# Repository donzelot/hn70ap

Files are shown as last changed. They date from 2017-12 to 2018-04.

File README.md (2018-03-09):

# hn70ap
Development board for modern packet radio on UHF

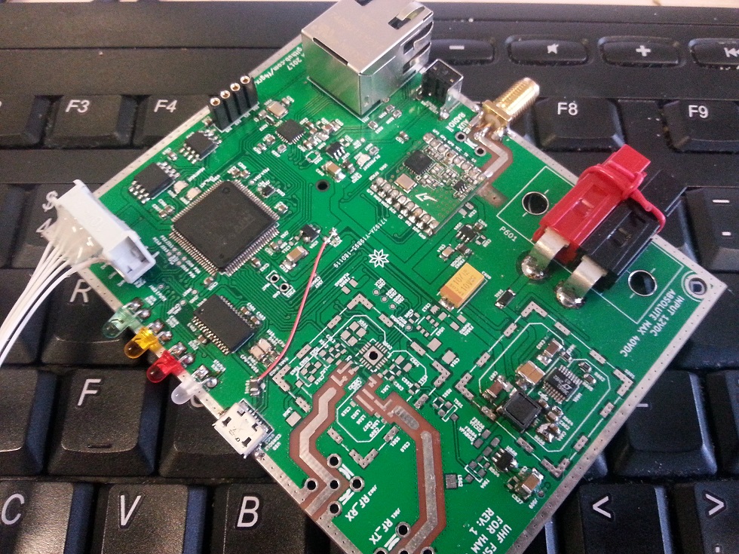
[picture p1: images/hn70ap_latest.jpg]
device under construction picture of device assembly


This repository contains sources for a few kicad projects and a NuttX board
support package for the board.

The main schematic and additional schematics and board designs are released
under the CERN OHL license.

Prerequisites
=============
 * linux (in 2017 there are many ways to get that)
 * a micro-usb cable to see the debug uart output
 * a jtag/swd adapter
 * a working openocd installation
 * an arm-none-eabi toolchain: https://launchpad.net/gcc-arm-embedded
 * to change the default configs: install kconfig-frontends
 
Mandatory: Install toolchain
============================
The arm-none-eabi toolchain provided by your distro probably does not work OK
(from experience). You may be lucky but this is not widespread enough. So we're
installing a really working toolchain.

The hardest way: compile a toolchain
------------------------------------
Hey this is a beginner guide. you dont need my guide if you are doing that. Help
yourself!

The hard way: download and install
----------------------------------

Open a bash shell console, then type commands ONE BY ONE (adapt them if you know
what you are doing):
```
$ cd $HOME
$ mkdir toolchains
$ cd toolchains
$ wget -O toolchain.tar.bz2 https://launchpad.net/gcc-arm-embedded/5.0/5-2016-q3-update/+download/gcc-arm-none-eabi-5_4-2016q3-20160926-linux.tar.bz2
$ tar jxvf toolchain.tar.bz2
$ cd $HOME
$ export PATH=$PATH:$HOME/toolchains/gcc-arm-none-eabi-5_4-2016q3/bin
```
The last line makes the ARM compiler available in your shell environment. You
can make that automatic, search the web. Otherwise you have to execute this last
line in each new shell window.

The easy way for ubuntu based distros
-------------------------------------

There is a ppa
```
sudo add-apt-repository ppa:team-gcc-arm-embedded/ppa
sudo apt-get update
sudo apt-get install gcc-arm-embedded
```

Toolchain test
--------------

You can test that the toolchain is functional by typing this command and
expecting this answer:
```
$ arm-none-eabi-gcc
arm-none-eabi-gcc: fatal error: no input files
compilation terminated.
```

If the command is not found, then the toolchain is not correctly installed and
the following will NOT work.

Optional: kconfig-frontends
===========================
Skip for now.
TODO, https://bitbucket.org/nuttx/tools, ./configure && make && make install

openocd
=======
Skip for now. TODO apt-get or ./configure && make && make install

Basic Build
===========
You need a working NuttX development environment:

```
$ mkdir nuttx
$ cd nuttx
$ git clone https://bitbucket.org/nuttx/nuttx
$ git clone https://bitbucket.org/nuttx/apps
$ cd nuttx
```
Then you can clone the board config in the proper directory
(This is NOT a submodule!)
```
$ cd configs
$ git clone https://github.com/f4grx/hn70ap
$ cd ..
```

Then choose any of the following test configurations
```
$ tools/configure.sh hn70ap/build/0_boot
```
```
$ tools/configure.sh hn70ap/build/1_memories
```
```
$ tools/configure.sh hn70ap/build/2_oled
```
And build the binary image for this board:
```
$ make
```
This should end up with an ELF binary 'nuttx', and binary images nuttx.bin

You then have to flash this binary on your board, probably with OpenOCD.

This will give you a basic shell, type help to show basic commands. This can be used to validate the behaviour of the board's CPU.

Flashing without JTAG
=====================

This will be possible later, when the bootloader is made ready. The hardware is ready to support that.
A python tool will build an update image from the nuttx elf output, and you will be able to send that image via ethernet or serial.

The bootloader is currently being written. The algorithm is as follows: At CPU startup, the external flash is initialized and searched for a firmware update, except when the button is pressed. If the update is valid, it is applied. If a failure happens, or the button has been pressed, enter a serial download mode. This mode will expect a firmware update image on the serial port and then write it to the external flash. Once done, an update attempt will be attempted after a reboot.

Advanced build
==============
More configurations will be added later that can be used to test ethernet, spi/i2c memories, etc

To modify the nuttx options type make menuconfig and mess around.

To get useful behaviour from this board you will need to add some applications that are not developed yet.

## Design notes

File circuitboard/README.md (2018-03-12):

Circuit board for hn70ap
========================

This folder contains the schematic of the KiCAD board used by the hn70ap
project.

It is released under the CERN OHL.

The project is completely standalone, it does not depend on ANY external
schematic library.

To open it you need kicad version 4.0.7.

Enclosure
=========
Any enclosure that can host a 80x100mm PCBs with connectors on both 100mm
sides is usable, for example a slotted extrusion box. I am using a
Multicomp MCREBS80 box from Farnell, which is in fact a Box Enclosures B2-080.
https://www.boxenclosures.com/product-category/bex-series-anodized-extruded-aluminum-enclosures/bex-series-2/

Power supply
============
 * Input via Anderson PowerPole for standard 13.8V ham
 * LTC3646 Creates a 5V 1A rail
 * Each component (radios, CPU, ethernet) has a ferrite bead then big storage
capacitor followed bu 3V3 LDO. Radios can reach 100mA each, Ethernet is max
40 mA, CPU is much lower.
 * When using the RF4463 1W module instead of the RFM26, we need a clean 5V
regulated with a LDO, so the LTC is configured for 5.5V instead.
 
Clocks
======
 * Ethernet PHY has a 25 MHx XTAL that gets doubled in the PHY to generate the
RMII reference clock
 * SI4463 has a 30 MHz XTAL for its own use, but a footprint is available for a
5x3.2mm TCXO via an UFL, which can also be used to feed an external reference.
 * CPU HSE is connected to a 20 MHz xtal to reach its max clock speed of 180 MHz
with correct accuracy
 * CPU 32 kHz clock is connected to a cylindrical watch xtal

Another design that I know has the 25 MHz xtal on the cpu, then feeds a 25 MHz
MCO line to the PHY, which doubles it and feeds it back to the RMII clock input.
Weird CPU delay loop calculations, long RF lines, not good.

CPU peripheral connections
==========================

Ethernet
--------

The STM32 Ethernet Peripheral is connected to a KSZ8081RNA PHY via RMII. 50 MHz
RMII Clocking is provided via a 25 MHz XTAL doubled by the PHY. Current status:
soldering failed, waiting for a new device to install.

```
RX0    PC4/33
RX1    PC5/34
CRSDV  PA7/32
TX0    PB12/51
TX1    PB13/52
TXEN   PB11/48
REFCLK PA1/24
IRQ    PE12/43
MDIO   PA2/25
MDC    PC1/16
```

Some GPIOs are used to indicate the link status and reset the PHY:

```
MAC_LINK PD8/55 Open Drain output for a LED
MAC_RST  PB0/35
```

Debug UART
----------
This uart is used to display the NuttX console. It is connected to UART4 (not an
USART). It runs at 230400 bauds, 8N1. The FTDI chip is powered via USB only, so
UART LEDs are not powered when USB is not connected. Current status: Hardware
working, but current PCB footprint has an issue.

```
TXD4  PC10/78 (AF8)
RXD4  PC11/79 (AF8)
```

SPI Flash
---------
This memory is used to store the firmware update to be programmed by the
bootloader, and a flash filesystem for file storage. It is connected to bus
SPI2. Current status: Validated in hardware and software.

NuttX creates two partitions on it:
* a 2 MB partition for firmware updates
* a 6 MB partition for data storage

```
MOSI2  PB15/54 (AF5)
MISO2  PB14/53 (AF5)
SCLK2  PB10/47 (AF5) - via pin PD10/57 to help routing
CS     PA9/68
```

I2C EEPROM
----------
This memory stores the Ethernet MAC address and generic non volatile parameters
that must survive reset. The device is connected to I2C3. The I2C bus is also
available on a pin header, can be used to add some daugterboards. The pinout is
compatible with standard I2C OLED screens based on the SSD1306 controller. Some
configurations enable support for this screen so debug information can be
displayed. Current status: Validated in hardware and software.

```
SDA3  PC9/66 (AF4)
SCL3  PA8/67 (AF4)
```

Main radio transceiver
----------------------
The main radio transceiver is a si4463 with separate TX and RX signals along
with commutation signals in the form of 5V DC bias on the RF lines. It can be
connected to external RF hardware (LNA/PA/Switch). Using BOM components, it is
RF matched for the 430-440 MHz frequency band, but you can tweak components for
any frequency of your choice (have a look at Silabs app notes). The device is
connected to SPI4.

```
MOSI4  PE6/5 (AF5)
MISO4  PE5/4 (AF5)
SCLK4  PE2/1 (AF5)
CS     PE4/3
IRQ    PC13/7
SDN    PE3/2 Used to reset BOTH radio chips in a clean way
```

Auxiliary radio transceiver
---------------------------
The auxiliary radio transceiver is either an off-the-shelf RFM26W from HopeRF
(20 dBm output power) or a RF4463F30 (high power, 30 dBm). These are also based
on the Silabs si4463. The matching is on-board and there are several frequency
bands available. The device shares the same SPI4 bus as the main transceiver.
SDN line is shared with the main transceiver, IRQs are separate.

```
CS    PA3/26
IRQ   PA6/31
```

Power supply
------------
The switching regulator provides a PGOOD output that is asserted while the
output voltage is within a 5% tolerance. This can be used to prevent writes to
the external SP flash if the power is about to fail.

```
PGOOD  PC0/15
```

LEDs
----
Informative LEDs are available. They are connected to the supply voltage and
their GPIO pins are configured as open drain, except for the bicolor LED.
Signification of external LEDs may change in the future.

```
D301 (Panel)    PB9/96 + PE0/97 (Bicolor Green/Red - Status)
D302 (Panel)    PB8/95  (Blue - Clients connected)
D303 (Panel)    PB7/93  (Orange - Transmit)
D304 (Panel)    PB6/92  (Green - Receive)
D305 (Internal) PD15/62 (Ay color - Heartbeat)
D306 (Internal) PD11/58 (Any color - CPU Activity)
J201 (Ethernet) PD8/55  (Ethernet link status)
```

These LEDs are not driven by the CPU:

```
D602 (Power)    ---     (Blue)
D401 (Internal) ---     (Any color - FTDI TX)
D402 (Internal) ---     (Any color - FTDI RX)
J201 (Ethernet) ---     (Ethernet activity)
```

Button
------
A push button with a 100nF debounce to ground and a pull-up is available for misc functions.
If the button is pressed at power up, the bootloader will enter the serial download mode without
even looking at the external flash contents.

```
BUTTON PE11/42
```

eof

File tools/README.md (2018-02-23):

The hn70ap bootloader
=====================

The firmware on the hn70ap board can be directly flashed via JTAG. It can also
be updated using a dedicated process that does not required JTAG.

How it works
------------

The hn70ap board features an on-board 64 Mb (8 Mbytes) flash memory that is
logically split into two partitions:

 * a 2 MB firmware update partition,
 * a 6 MB a storage partition.

(Note: The next revision will hold two flash chip, and a kind of "RAID0" driver
will be used to aggregate the storage partition and the memory on a secondary
flash.)

Some firmware tools are available to download a firmware update image and store
it in this external flash. The download process can happen via Ethernet, serial,
or serial in the bootloader mode (failsafe recovery mode).

The internal STM32 flash memory is also logically split into two parts:
 * the bootloader, occupies the first sector (16kB) of the internal STM32 flash
(address range 0x08000000 - 0x08004000).
 * the user software, in the other sectors (starting at 0x08004000)

This means is that instead of directly starting to execute the user
software, the CPU always starts to execute inside the bootloader. The bootloader
runs some update process described later, then remaps the CPU vector table to
the beginning of the user software using the ARM VTOR register, setups the
stack pointer defined in the zeroth vector, and jumps to the address stored in
the first vector, as would be done by the CPU startup procedure.

In the original NuttX firmware, this address map is ensured by the project's
linker script, that justs makes the linker believe that the main .text section
starts at this 0x08004000 address instead of 0x08000000. No other change is
required in the NuttX RTOS. If you want to use a custom firmware, you have to
make sure that you skip the first 16 kbytes of the flash.

Once the firmware update image has landed in the external flash, the bootloader
can check that an update is present by looking at the image header in the first
256 bytes of the external flash. The first 4 bytes are the CRC32 of the next
252 bytes. If the image header is found valid, the update stored in the
following pages is programmed in the internal STM32 flash. If not valid, the
update partition is wiped before the current user software starts.

After having erased and reprogrammed the internal STM32 flash, the update
partition is then wiped.

The bootloader itself writes protects itself during its startup process, so it
cannot be erased inadvertently. If a bug is found during the life of the
product, the bootloader will be forced to update via a specific process.

Update failures
---------------

We have to be sure that the update process cannot brick the board. We believe
that it is not possible to end up with a board that cannot boot any software
because
 * the bootloader is write protected as soon as it starts
 * Any power interruption during the erase or programming of the internal
flash will trigger another attempt at next power cycle
 * Internal flash is verified before the external flash is wiped
 * Any invalid image is detected before any update takes place.

These reasons make us believe that the update process as designed is safe.
However, implementation bugs are still possible.

If the stm32 flash becomes erased, power is interrupted, and, because of this,
the external flash contents become invalid (which is highly unlikely), the
update will actually fail, and the bootloader will attempt to start an half
erased or half programmed stm32, while the external flash has become
unusable. This particular section cannot be detected at the
moment, but the update button can still be pressed to trigger a serial
downloader that will be able to put a new update image in the external flash.

Firmware update image format
============================

The following paragraph describes the layout of the firmware update image.

The image has two parts:
 * a 16k header (that replaces the bootloader contents, which is not stored in
the firmware update image)
 * a variable length memory image

Header
------

Note: bits in bytes are enumerated the natural way, b7 = 0x80 and b0 = 0x01.

The first 256 bytes of the update image contains critical information related
to the update. The first 4 bytes are the CRC-32 (ZIP or GZIP algorithm) of the
next 252 bytes. If the CRC is not valid, the update is not applied by the
bootloader.
The next 252 bytes contain a sequence of TLV elements. TLV elements are a
nestable binary data structure similar to BER or DER, but simpler. This
structure easy future extensions.

TLVs have 3 fields:
 * a TAG: actually a bit field. It indicates a tag number, a tag class, a bit
indicating if the tag data field is raw or contains more tag.
* a LENGTH: this one describes how many bytes are in the payload (value).
Lengths from 0 to 127 are encoded as one byte, longer lengths are encoded as a
first byte (0x80 + number of bytes needed to encode actual length) followed by actual
length encoded in that number of bytes.
* a VALUE: can be raw bytes or nested tags according to the TAG.

Tag encoding table:
```
76543210
00...... Universal tag class - basic types
01...... Application class - defined by a norm
10...... Context specific class - depends on parent tag
11...... Private class (we will use this)
..0..... Primitive data object (Value contains bytes)
..1..... Constructed data object (Value contains more tags)
...xxxxx Tag value from 0 to 30
...11111 Reserved tag signaling the use of a second tag byte
```

Some of this info is also described here:
https://www.openscdp.org/scripts/tutorial/emv/TLV.html

The following private tags are used to describe some metadata about the update:
```
0xC0 - User software size (4 bytes, required)
0xC1 - Major version (1 byte, optional)
0xC2 - Minor version (1 byte, optional)
0xC3 - CRC32 of the user software (4 bytes, required)
0xC4 - SHA256 of the user software (32 bytes, optional)
```

If multiple tags are defined, which is not normally done by the generation
tool, then the first values are used.

The tags are padded with 0xFF (invalid tag) to a length of 16384 bytes. In the
future this space will be usable to hold firmware signatures.

Image
-----
The image is nothing special. It just contains bytes that represent the user
software. The length of this part is equal to the value indicated in tag 0x80.

Firmware update tool
====================

This tool is written in python. It reads memory segments from an ELF file and
writes the firmware image. If a symbol table is found, the hn70ap entry is
searched and its content is used to initialize the header.

eof

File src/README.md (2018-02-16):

The port is made of multiple files with the following roles

hn70ap_boot.c:
   - Contains the entry point to initialize all board related stuff.
     This function is called early in the boot and can ONLY initialize
     low level stuff like GPIO lines. NO DEVICE should be registered here
     since the OS has not been initialized yet.

hn70ap_spi.c:
   - Initialize CS lines
   - Define callbacks for peripheral selection

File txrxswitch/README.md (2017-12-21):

This folder contains a complete, stand-alone kicad project for a fast TX/RX switch that could be used with the main hn70ap circuit.

The design is experimental, in particular, I have no idea if isolation between the tx and rx branches is enough.

The project is released under the CERN OHL (schematic and board).

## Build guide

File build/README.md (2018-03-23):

BUILD CONFIGURATIONS

This directory contain canned build configurations for the hn70ap board. Each of
them starts with a number that represents a test order.

0_boot: This configuration does nothing more than a hello world. It will blink
the HEARTBEAT LED and stop here. NuttX shell will not start. This can be used
to check that the CPU is booting using the external 20 MHz XTAL. This
configuration does not contain a bootloader, so it can only be installed via
JTAG, and it cannot be upgraded.

1_memories: This configuration enables the external EEPROM and FLASH memories.
Then it tries to read the SST26 unique identifier and the MAC address stored
in the EEPROM. This configuration does not contain a bootloader and can only
be installed via JTAG, and it cannot be upgraded.

2_oled: This configuration contains initialization code and drivers for a small
OLED screen on the i2c bus. It contains a "fb" example application that will
draw some rectangles on the screen. It also initializes the external memories.

This configuration contains the full bootloader and an application
that can receive a software update from the serial console, then write it to
the bootloader partition, then reboot. After the reboot, the bootloader will
check the validity of the contents in the external flash, and if an update is
present, it will copy it into the internal STM32 flash memory, then transfer
control to it. You can use the hn70ap_makeupdate utility to build an updater
image to be sent to the board. You can use the hn70ap_serialupdate utility
to transfer the update to the board.

3_ethernet: This configuration will attempt to initialize the external PHY and
internal MAC. Then a daemon is started in the background to manage link up/down
events, and start a DHCP request when the link is up.

4_auxradio: This configuration will attempt to detect and initialize the
auxiliary radio module connected to the board. It requires a specific branch
of the NuttX code that contains the proper radio driver, found at:

https://bitbucket.com/slorquet/nuttx/branches/radio

This branch contains development code for the si4463 driver. For the moment
a canned config generated by SiLabs WDS is used, but the goal is to reverse
engineer this tool and allow the user to configure the radio at runtime.
Once development is finished, this driver will be added to the official NuttX
tree, but this event is not expected to happen soon.

Other configurations assume a fully functional board, and are made for real
hn70ap applications, eg router, access point, freedv hotspot.
They will be defined later.

full: This is the latest configuration. It contains code to initialize all
peripherals and boots the hn70ap system daemon that will mount the flash file
system, initialize EEPROM settings, then start the shell.

beacon: This configuration initializes the aux radio and does not have
ethernet enabled. At boot, the beacon app is autostarted, and the code sends
regular data packet on 435 MHz. This is currently used on a secondary board
to test packet reception on my main prototype board.

Applications
============

beacon: A radio beacon that sends data on the air, until the board is stopped.
Future improvements will start a background thread and leave the shell available
so the beacon can be stopped.

config: This tool can be user to manipulate the contents of the configuration
EEPROM. You can list and change settings.

update: A firmware updater that is able to download a new firmware image in the
external flash. Download can be made via a serial port (via the console) or via
tftp (this is faster). Future improvements will support the use of LZF
compression to speed up the data transfer.

sysdaemon: This is the main hn70ap application. It is started on boot in most
useful configuration. The tool initializes some executive framework that will
 - init and read the configuration settings in the EEPROM
 - mount the external flash SMART filesystem
 - start a network monitor to detect cable insertion/removal events, and start
   DHCP operations (if enabled) right after the cable is detected.

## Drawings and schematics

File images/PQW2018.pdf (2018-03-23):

### The hn70ap project

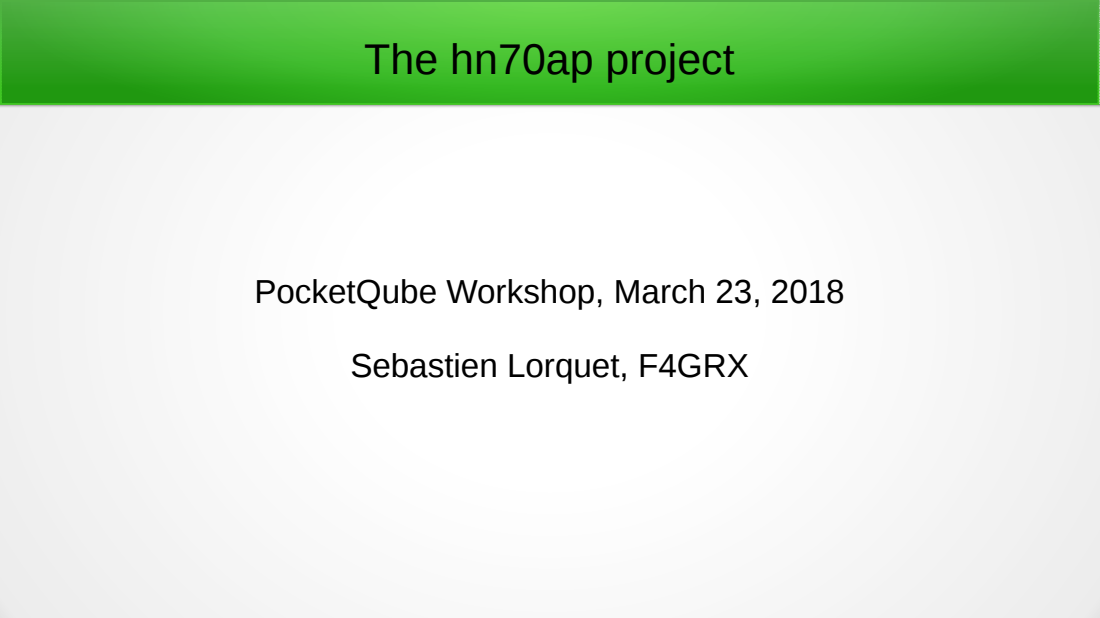
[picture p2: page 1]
Sebastien Lorquet, F4GRX

PocketQube Workshop, March 23, 2018

### Who am I

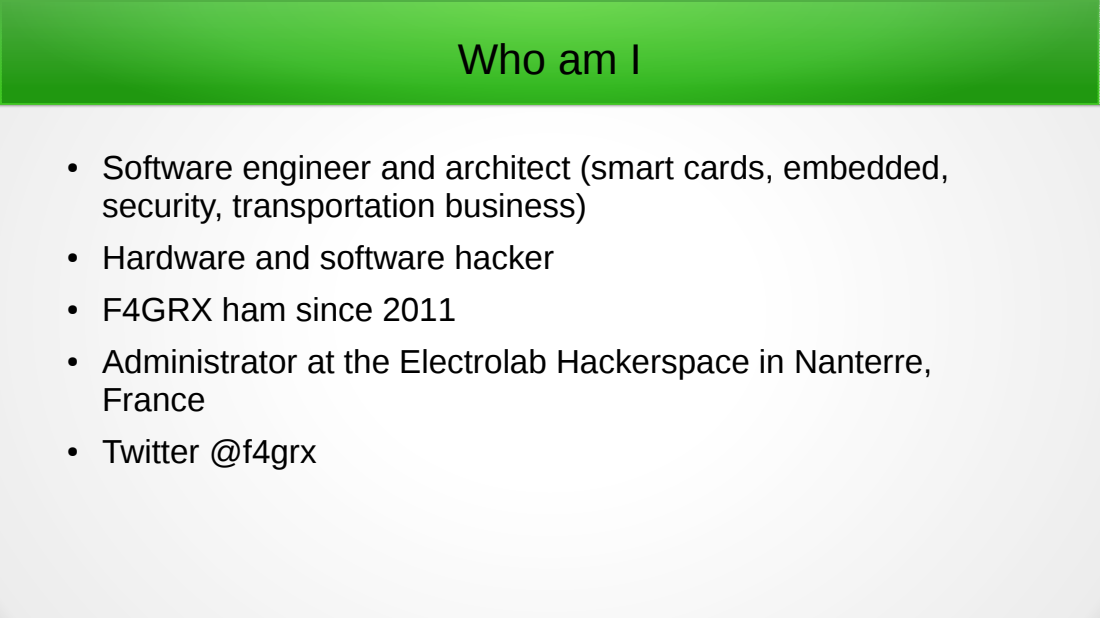
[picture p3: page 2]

● Software engineer and architect (smart cards, embedded,
security, transportation business)
● Hardware and software hacker
● F4GRX ham since 2011
● Administrator at the Electrolab Hackerspace in Nanterre,
France
● Twitter @f4grx

### The Electrolab hackerspace

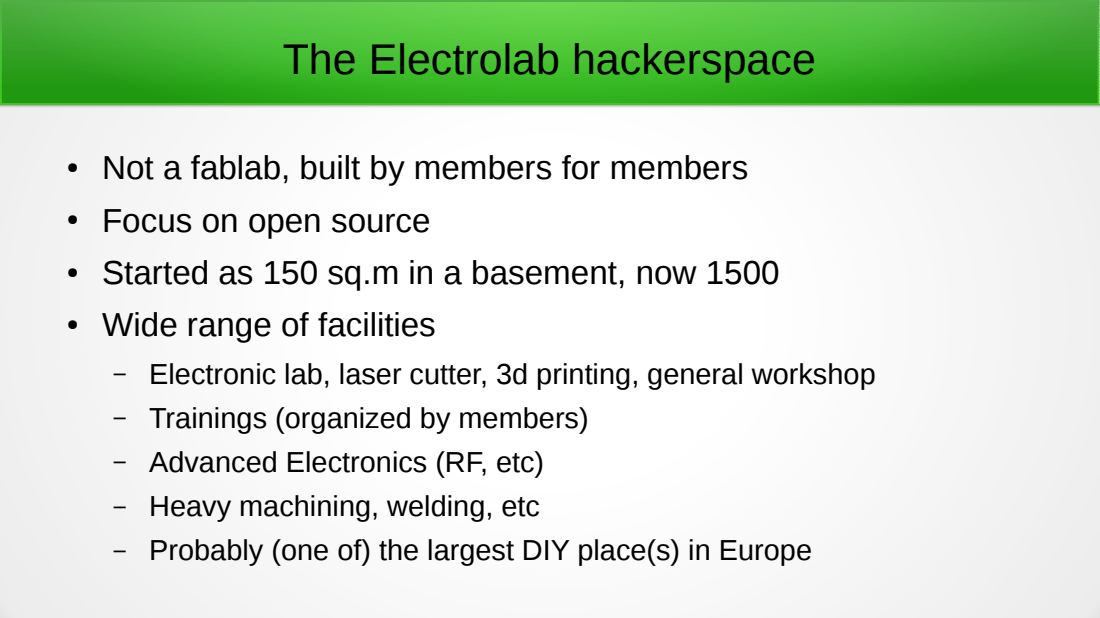
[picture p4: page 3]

● Not a fablab, built by members for members
● Focus on open source
● Started as 150 sq.m in a basement, now 1500
● Wide range of facilities
– Electronic lab, laser cutter, 3d printing, general workshop
– Trainings (organized by members)
– Advanced Electronics (RF, etc)
– Heavy machining, welding, etc
– Probably (one of) the largest DIY place(s) in Europe

### Having fun at the Electrolab

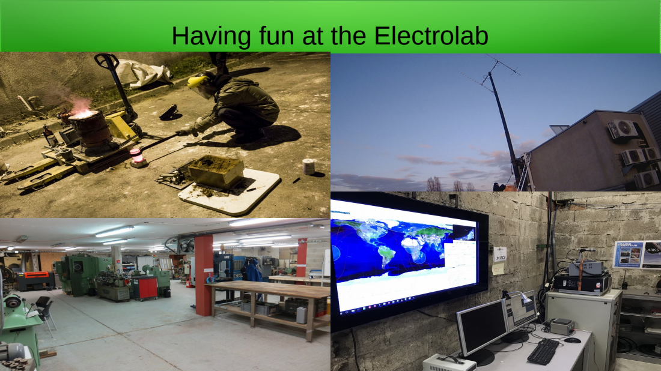
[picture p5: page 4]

### Space at the Electrolab

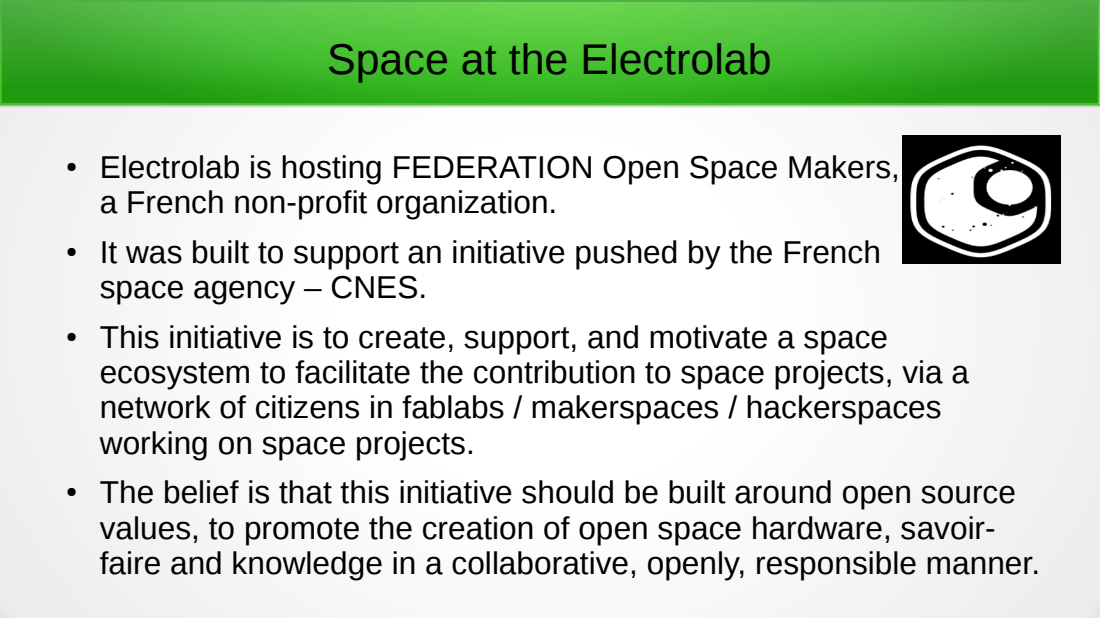
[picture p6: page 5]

● Electrolab is hosting FEDERATION Open Space Makers,
a French non-profit organization.
● It was built to support an initiative pushed by the French
space agency – CNES.
● This initiative is to create, support, and motivate a space
ecosystem to facilitate the contribution to space projects, via a
network of citizens in fablabs / makerspaces / hackerspaces
working on space projects.
● The belief is that this initiative should be built around open source
values, to promote the creation of open space hardware, savoir-
faire and knowledge in a collaborative, openly, responsible manner.

### hn70ap « HamNET 70cm Access Point »

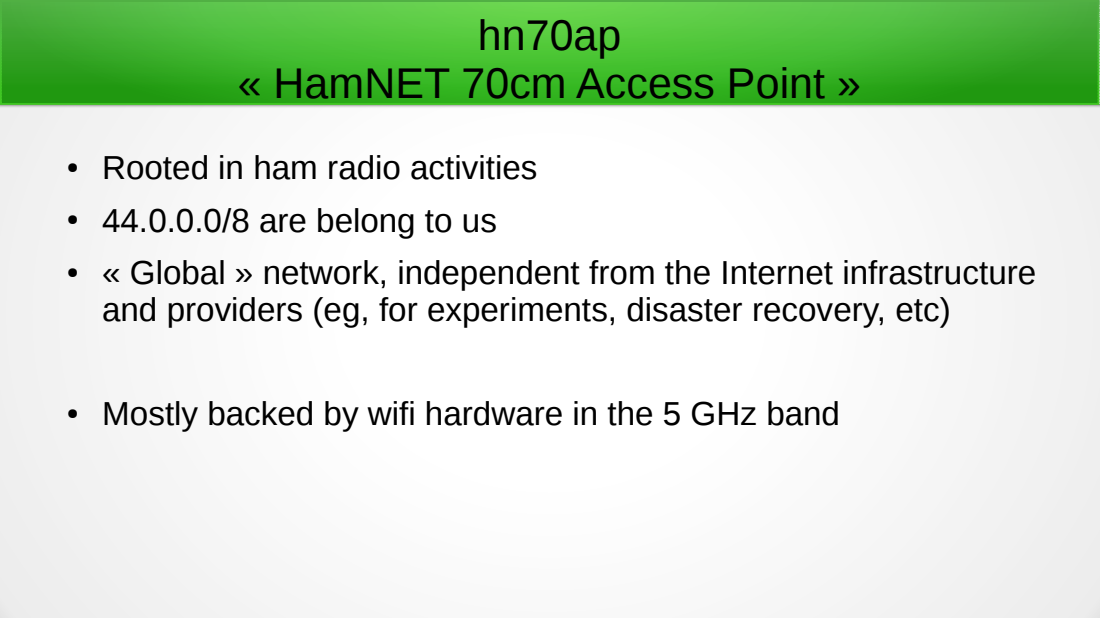
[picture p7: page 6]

● Rooted in ham radio activities
● 44.0.0.0/8 are belong to us
● « Global » network, independent from the Internet infrastructure
and providers (eg, for experiments, disaster recovery, etc)

● Mostly backed by wifi hardware in the 5 GHz band

French deployment is far from ideal...

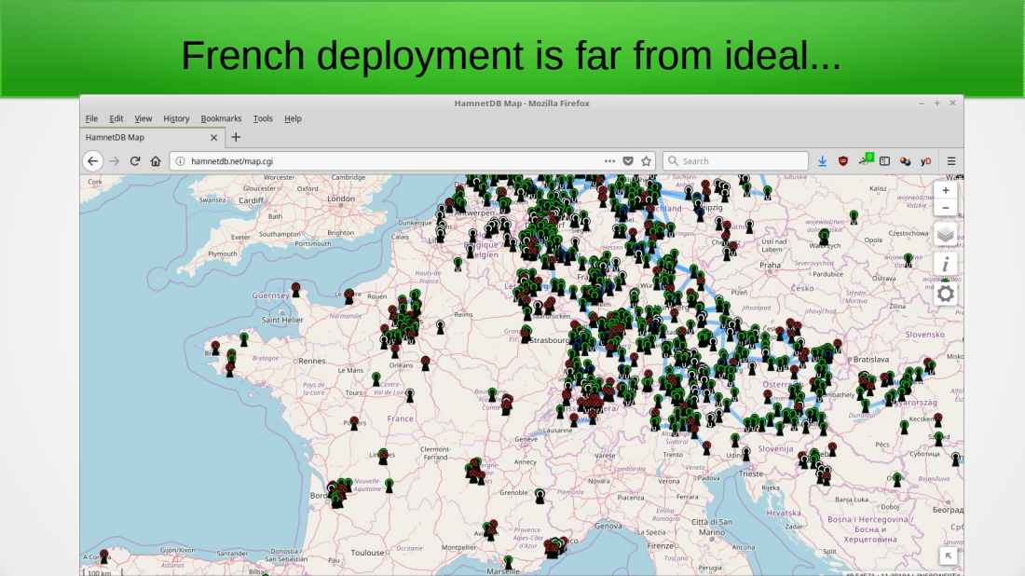
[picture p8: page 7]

### But there’s more than ham radio

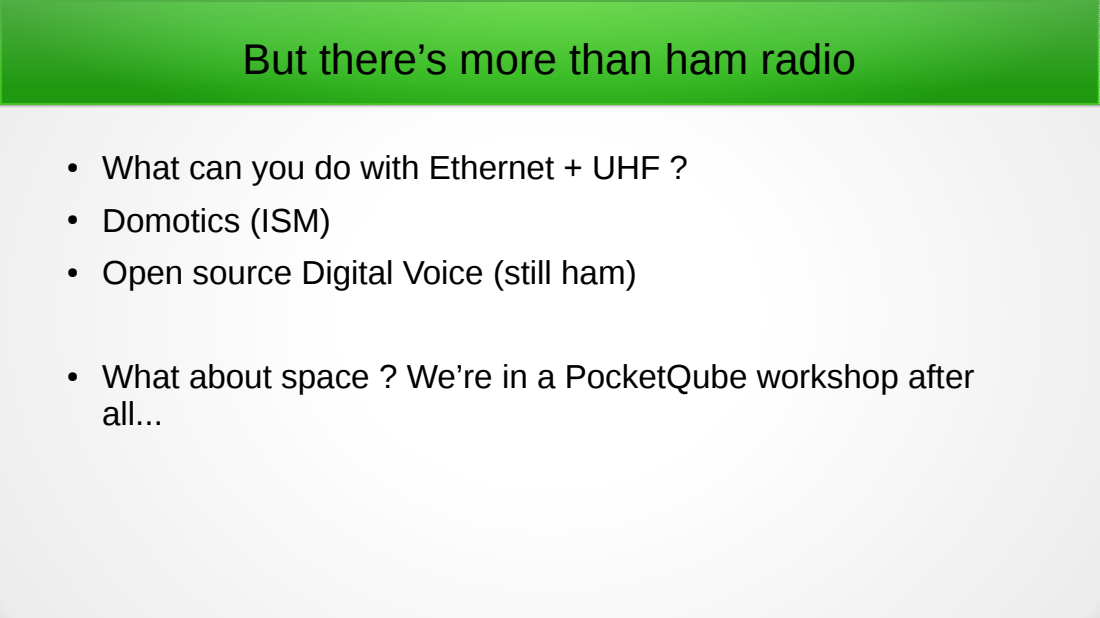
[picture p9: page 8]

● What can you do with Ethernet + UHF ?
● Domotics (ISM)
● Open source Digital Voice (still ham)

● What about space ? We’re in a PocketQube workshop after
all...

### hn70ap as a small sat base station

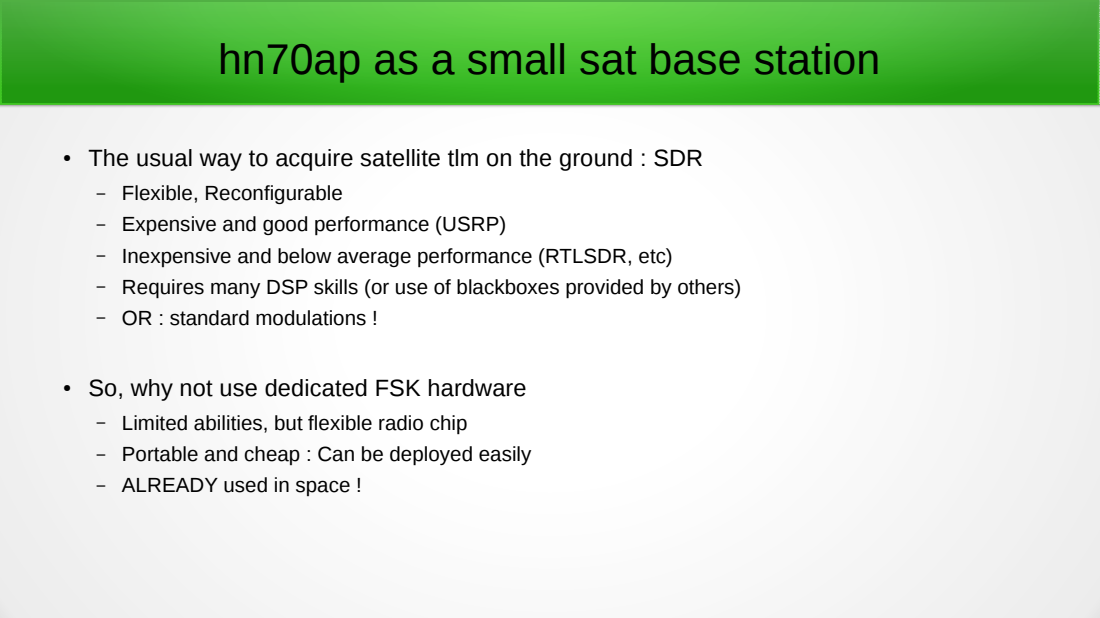
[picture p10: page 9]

● The usual way to acquire satellite tlm on the ground : SDR
– Flexible, Reconfigurable
– Expensive and good performance (USRP)
– Inexpensive and below average performance (RTLSDR, etc)
– Requires many DSP skills (or use of blackboxes provided by others)
– OR : standard modulations !

● So, why not use dedicated FSK hardware
– Limited abilities, but flexible radio chip
– Portable and cheap : Can be deployed easily
– ALREADY used in space !

### How it’s made

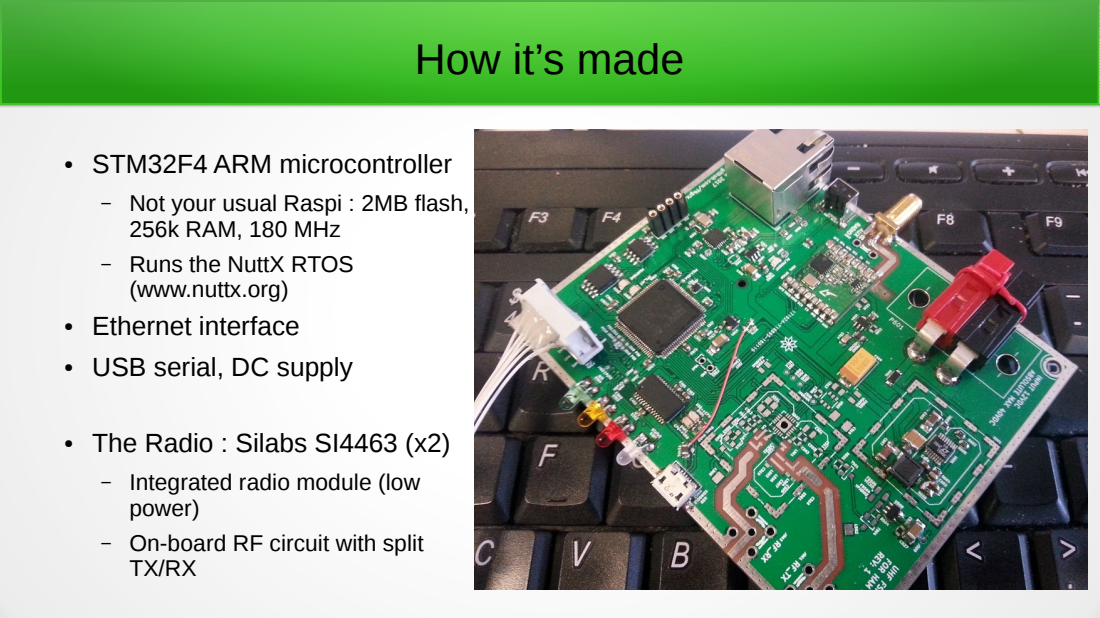
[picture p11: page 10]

● STM32F4 ARM microcontroller
– Not your usual Raspi : 2MB flash,
256k RAM, 180 MHz
– Runs the NuttX RTOS
(www.nuttx.org)
● Ethernet interface
● USB serial, DC supply

● The Radio : Silabs SI4463 (x2)
– Integrated radio module (low
power)
– On-board RF circuit with split

### Silicon Labs si4463

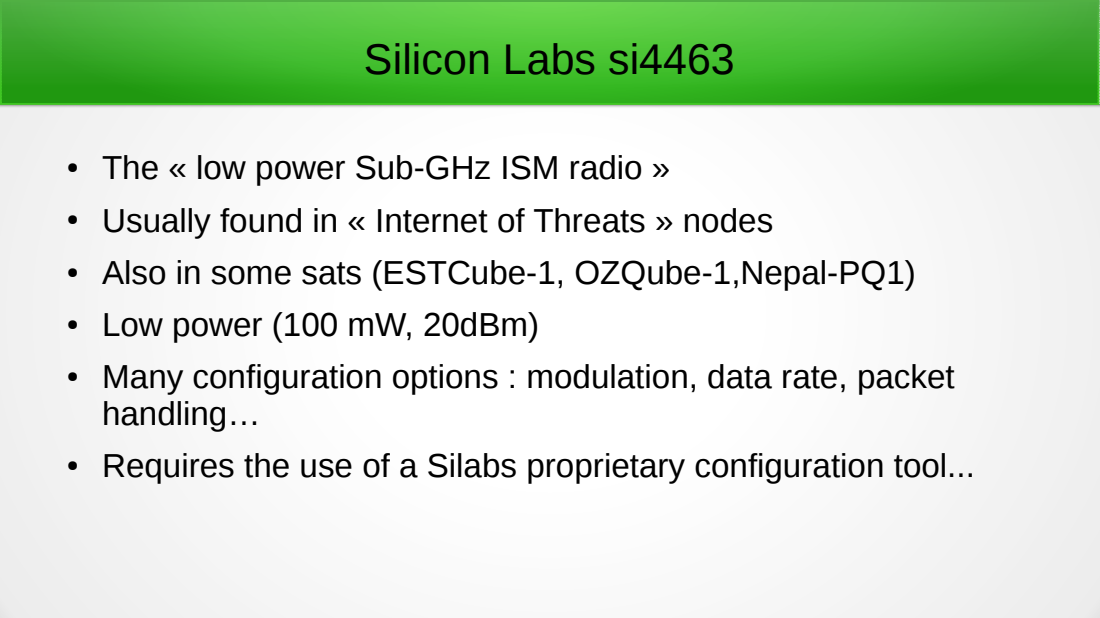
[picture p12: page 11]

● The « low power Sub-GHz ISM radio »
● Usually found in « Internet of Threats » nodes
● Also in some sats (ESTCube-1, OZQube-1,Nepal-PQ1)
● Low power (100 mW, 20dBm)
● Many configuration options : modulation, data rate, packet
handling…
● Requires the use of a Silabs proprietary configuration tool...

### Dear Silabs, can you help ?

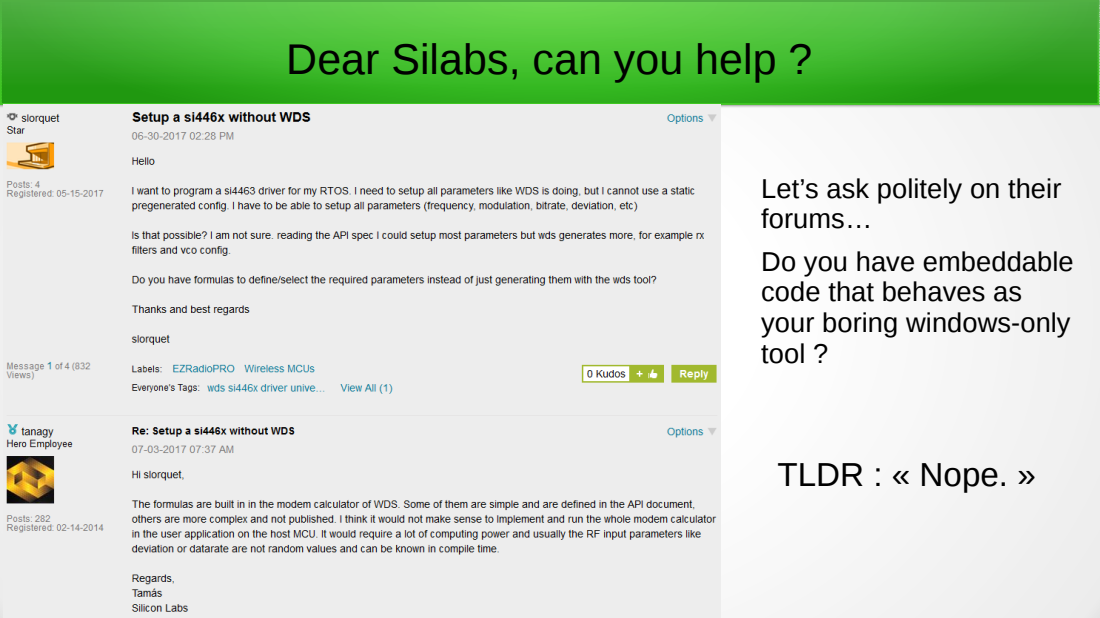
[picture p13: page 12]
TLDR : « Nope. »

Let’s ask politely on their
forums…
Do you have embeddable
code that behaves as
your boring windows-only
tool ?

### Zoom and Enhance !

C# and precompiled Python; Hold my beer ! Work in progress. ⇒

● « No » is not a valid answer to a hacker.
● Let’s reverse engineer and see what’s under the hood

● The SI4463 has better abilities than just ISM with a fixed config

● External RF hardware (PA, LNA, switches, filters) is possible
● Tuner can operate in the full « 70cm » (430-440 MHz) ham band among others
● Can be used as an intermediate frequency for higher bands (L, S, X bands) with
transverters

● Radar bands : L : 1-2 GHz , S : 2-4 , C : 4-8, X : 8-12 GHz, Ku : 12-18 Ka : 18-40

### Current status


● Hardware prototype is working, radio hacking in progress

● Rework and BOM optimization needed
– Fix v1 mistakes, simplify

● Project diffusion
– Code and Kicad at https://github.com/f4grx/hn70ap
– Cheap PCB for DIY builders (on demand)
– Commercial units : it’s complicated...








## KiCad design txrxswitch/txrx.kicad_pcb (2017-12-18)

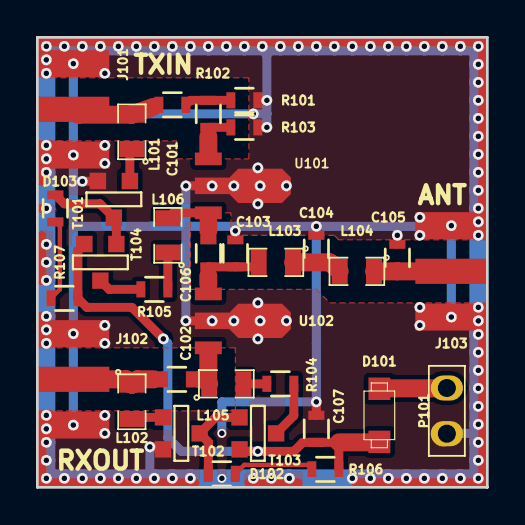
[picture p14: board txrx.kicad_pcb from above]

Board: 2 copper layers, 25.0 x 25.0 mm, 33 parts (0 on the bottom side), 22 nets.

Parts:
C101, C102, C103, C104, C105, C106, C107: 100p; 0603_m1608
D101: DIODE; SOD123
D102, D103: LED; 0603_m1608
J101, J102, J103: SMA; SMA_EDGE_NRW
L101, L102: 3u3; 0805_m2012
L103, L104, L105, L106: LSMALL; 0805_m2012
P101: CONN_01X02; PINS-2.54-1x2
R101, R102, R103, R104, R105, R106, R107: RSMALL; 0603_m1608
T101, T102: MOSN_SMALL; SOT23GDS
T103, T104: MOSP_SMALL; SOT23GDS
U101: MMIC_SMALL; SOT89
U102: PGA-103+; SOT89

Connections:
GND: C103.1, C104.1, C105.1, C107.1, J101.2, J102.2, J103.2, P101.2, R101.2, R103.2, T101.S, T102.S, U101.2, U102.2
unnamed: C101.1, R101.1, R102.1
unnamed: C101.2, J101.1, L101.2
unnamed: C102.1, L105.1, U102.3
unnamed: C102.2, J102.1, L102.1
unnamed: C103.2, C106.1, L103.2, U102.1
unnamed: C104.2, L103.1, L104.2
unnamed: C105.2, J103.1, L104.1
unnamed: C106.2, L106.2, U101.3
unnamed: D101.A, P101.1
unnamed: D102.1, R106.2
unnamed: D102.2, T102.D, T103.G
unnamed: D103.1, R107.2
unnamed: D103.2, T101.D, T104.G
unnamed: L101.1, T101.G
unnamed: L102.2, T102.G
unnamed: L105.2, R104.1
unnamed: L106.1, R105.2
unnamed: R102.2, R103.1, U101.1
unnamed: R104.2, T103.D
unnamed: R105.1, T104.D
VDD: C107.2, D101.K, R106.1, R107.1, T103.S, T104.S

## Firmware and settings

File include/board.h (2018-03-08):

/*******************************************************************************
 * configs/hn70ap/include/board.h
 * include/arch/board/board.h
 *
 *   Copyright (C) 2012, 2015-2016 Gregory Nutt. All rights reserved.
 *   Author: Gregory Nutt <gnutt@nuttx.org>
 *   Copyright (C) 2018 Sebastien Lorquet. All rights reserved.
 *   Author: Sebastien Lorquet <sebastien@lorquet.fr>
 *
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
 * 1. Redistributions of source code must retain the above copyright
 *    notice, this list of conditions and the following disclaimer.
 * 2. Redistributions in binary form must reproduce the above copyright
 *    notice, this list of conditions and the following disclaimer in
 *    the documentation and/or other materials provided with the
 *    distribution.
 * 3. Neither the name NuttX nor the names of its contributors may be
 *    used to endorse or promote products derived from this software
 *    without specific prior written permission.
 *
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
 ******************************************************************************/

#ifndef __CONFIG_HN70AP_INCLUDE_BOARD_H
#define __CONFIG_HN70AP_INCLUDE_BOARD_H

/*******************************************************************************
 * Included Files
 ******************************************************************************/

#include <nuttx/config.h>

#ifndef __ASSEMBLY__
# include <stdint.h>
#endif

/*******************************************************************************
 * Pre-processor Definitions
 ******************************************************************************/

/* Clocking *******************************************************************/
/* The hn70ap board features a 20MHz crystal for HSI, and a 32kHz RTC backup
 * crystal.
 *
 * This is the canonical configuration:
 *   System Clock source           : PLL (HSE)
 *   SYSCLK(Hz)                    : 180000000    Determined by PLL config
 *   HCLK(Hz)                      : 180000000    (STM32_RCC_CFGR_HPRE)
 *   AHB Prescaler                 : 1            (STM32_RCC_CFGR_HPRE)
 *   APB1 Prescaler                : 4            (STM32_RCC_CFGR_PPRE1)
 *   APB2 Prescaler                : 2            (STM32_RCC_CFGR_PPRE2)
 *   HSE Frequency(Hz)             : 20000000     (STM32_BOARD_XTAL)
 *   PLLM                          : 20           (STM32_PLLCFG_PLLM)
 *   PLLN                          : 360          (STM32_PLLCFG_PLLN)
 *   PLLP                          : 2            (STM32_PLLCFG_PLLP)
 *   PLLQ                          : TODO         (STM32_PLLCFG_PLLQ)
 *   Main regulator output voltage : Scale1 mode  Needed for high speed SYSCLK
 *   Flash Latency(WS)             : 5
 *   Prefetch Buffer               : OFF
 *   Instruction cache             : ON
 *   Data cache                    : ON
 *   Require 48MHz for USB OTG FS, : Disabled
 *   SDIO and RNG clock
 */

/* HSI - 16 MHz RC factory-trimmed
 * LSI - 32 KHz RC
 * HSE - On-board crystal frequency is 20MHz
 * LSE - 32.768 kHz
 */

#define STM32_BOARD_XTAL        20000000ul

#define STM32_HSI_FREQUENCY     16000000ul
#define STM32_LSI_FREQUENCY     32000
#define STM32_HSE_FREQUENCY     STM32_BOARD_XTAL
#define STM32_LSE_FREQUENCY     32768

/* Main PLL Configuration.
 *
 * PLL source is HSE
 * PLL_VCO = (STM32_HSE_FREQUENCY / PLLM) * PLLN
 *         = (20,000,000 / 20) * 360
 *         = 360,000,000
 * SYSCLK  = PLL_VCO / PLLP
 *         = 360,000,000 / 2 = 180,000,000
 */

#define STM32_PLLCFG_PLLM       RCC_PLLCFG_PLLM(20)
#define STM32_PLLCFG_PLLN       RCC_PLLCFG_PLLN(360)
#define STM32_PLLCFG_PLLP       RCC_PLLCFG_PLLP_2
#define STM32_PLLCFG_PLLQ       RCC_PLLCFG_PLLQ(7)

#define STM32_SYSCLK_FREQUENCY  180000000ul

/* AHB clock (HCLK) is SYSCLK (180MHz) */

#define STM32_RCC_CFGR_HPRE     RCC_CFGR_HPRE_SYSCLK  /* HCLK  = SYSCLK / 1 */
#define STM32_HCLK_FREQUENCY    STM32_SYSCLK_FREQUENCY
#define STM32_BOARD_HCLK        STM32_HCLK_FREQUENCY  /* same as above, to satisfy compiler */

/* APB1 clock (PCLK1) is HCLK/4 (45MHz) */

#define STM32_RCC_CFGR_PPRE1    RCC_CFGR_PPRE1_HCLKd4     /* PCLK1 = HCLK / 4 */
#define STM32_PCLK1_FREQUENCY   (STM32_HCLK_FREQUENCY/4)

/* Timers driven from APB1 will be twice PCLK1 */

#define STM32_APB1_TIM2_CLKIN   (2*STM32_PCLK1_FREQUENCY)
#define STM32_APB1_TIM3_CLKIN   (2*STM32_PCLK1_FREQUENCY)
#define STM32_APB1_TIM4_CLKIN   (2*STM32_PCLK1_FREQUENCY)
#define STM32_APB1_TIM5_CLKIN   (2*STM32_PCLK1_FREQUENCY)
#define STM32_APB1_TIM6_CLKIN   (2*STM32_PCLK1_FREQUENCY)
#define STM32_APB1_TIM7_CLKIN   (2*STM32_PCLK1_FREQUENCY)
#define STM32_APB1_TIM12_CLKIN  (2*STM32_PCLK1_FREQUENCY)
#define STM32_APB1_TIM13_CLKIN  (2*STM32_PCLK1_FREQUENCY)
#define STM32_APB1_TIM14_CLKIN  (2*STM32_PCLK1_FREQUENCY)

/* APB2 clock (PCLK2) is HCLK/2 (90MHz) */

#define STM32_RCC_CFGR_PPRE2    RCC_CFGR_PPRE2_HCLKd2     /* PCLK2 = HCLK / 2 */
#define STM32_PCLK2_FREQUENCY   (STM32_HCLK_FREQUENCY/2)

/* Timers driven from APB2 will be twice PCLK2 */
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

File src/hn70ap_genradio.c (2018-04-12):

/****************************************************************************
 * configs/hn70ap/src/hn70ap_genradio.c
 *
 *   Copyright (C) 2018 Sebastien Lorquet. All rights reserved.
 *   Author: Sebastien Lorquet <sebastien@lorquet.fr>
 *
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
 * 1. Redistributions of source code must retain the above copyright
 *    notice, this list of conditions and the following disclaimer.
 * 2. Redistributions in binary form must reproduce the above copyright
 *    notice, this list of conditions and the following disclaimer in
 *    the documentation and/or other materials provided with the
 *    distribution.
 * 3. Neither the name NuttX nor the names of its contributors may be
 *    used to endorse or promote products derived from this software
 *    without specific prior written permission.
 *
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
 ****************************************************************************/

/************************************************************************************
 * Included Files
 ************************************************************************************/

#include <nuttx/config.h>

#include <stdint.h>
#include <stdbool.h>
#include <debug.h>
#include <errno.h>

#include <nuttx/spi/spi.h>
#include <arch/board/board.h>
#include <nuttx/wireless/generic/si4463.h>
#include <nuttx/wireless/generic/genradio.h>

#include <stm32.h>
#include "hn70ap.h"

#if defined(CONFIG_HN70AP_RADIO)

struct si4463_priv_s
{
  uint32_t gpio_irq; /* GPIO definition used for IRQ */
  xcpt_t handler;
  FAR void *arg;
};

/*******************************************************************************
 * Name: si4463_attach
 *
 * Description:
 *   Initialize required resources to enable si4463 IRQs.
 *   Called from driver code.
 *
 ******************************************************************************/

int si4463_attach(FAR const struct si4463_lower_s *lower, xcpt_t handler, FAR void *arg)
{
  struct si4463_priv_s *priv = lower->privpointer;
  priv->handler = handler;
  priv->arg     = arg;
  stm32_configgpio(priv->gpio_irq);
  return 0;
}

/*******************************************************************************
 * Name: si4463_enable
 *
 * Description:
 *   Enable or disable the required IRQ. Called from driver code.
 *
 ******************************************************************************/

void si4463_enable(FAR const struct si4463_lower_s *lower, int state)
{
  struct si4463_priv_s *priv = lower->privpointer;
  if(state)
    {
      stm32_gpiosetevent(priv->gpio_irq, /*rising*/ false, /*falling*/ true, /*event*/ false, priv->handler, priv->arg);
    }
  else
    {
      stm32_gpiosetevent(priv->gpio_irq, /*rising*/ false, /*falling*/ false, /*event*/ false, NULL, NULL);
    }
}

#if defined(CONFIG_HN70AP_MAINRADIO)
struct si4463_priv_s si4463_priv_main;
const struct si4463_lower_s si4463_lower_main =
{
  si4463_attach,
  si4463_enable,
  &si4463_priv_main
};
#endif

#if defined(CONFIG_HN70AP_AUXRADIO)
struct si4463_priv_s si4463_priv_aux;
const struct si4463_lower_s si4463_lower_aux =
{
  si4463_attach,
  si4463_enable,
  &si4463_priv_aux
};
#endif

/*******************************************************************************
 * Name: hn70ap_genradio_initialize
 *
 * Description:
 *   Initialize the on board radio transceivers.
 *
 ******************************************************************************/

int hn70ap_genradio_initialize(void)
{
  FAR struct genradio_dev_s *radio;
  int ret;
  FAR struct spi_dev_s *spi4;

  /* Initialize SPI bus */

  spi4 = stm32_spibus_initialize(4);
  if (!spi4)
    {
      _err("ERROR: FAILED to initialize SPI port 4\n");
      return -EIO;
    }

  _info("Strobing shutdown\n");
  /* Strobe the SDN pin to reset both devices */
  stm32_configgpio(GPIO_RADIO_SDN);
  stm32_gpiowrite(GPIO_RADIO_SDN, 1);
  up_mdelay(10);
  stm32_gpiowrite(GPIO_RADIO_SDN, 0);

  /* Initialize radio devices */

#if defined(CONFIG_HN70AP_MAINRADIO)
  _info("Prepare main radio\n");
  si4463_priv_main.gpio_irq = GPIO_IRQ_RADIOMAIN;
#if defined(CONFIG_HN70AP_MAINRADIO_TCXO)
  radio = si4463_init(spi4, 0, 25000000, SI4463_IO1, SI4463_IO3, false, true, &si4463_lower_main);
#else
  radio = si4463_init(spi4, 0, 30000000, SI4463_IO1, SI4463_IO3, false, false, &si4463_lower_main);
#endif
  if(radio==NULL)
    {
      _err("Unable to initialize main si4463\n");
    }
  else
    {
      _info("Initialized main radio\n");
      ret = genradio_register(radio, "/dev/rmain");
      if(ret)
        {
          _err("Failed to register si4463 /dev/rmain\n");
        }
      _info("Registered main radio\n");
    }
#endif

#if defined(CONFIG_HN70AP_AUXRADIO)
  _info("Prepare aux radio\n");
  si4463_priv_aux.gpio_irq = GPIO_IRQ_RADIOAUX;
  radio = RFM26_init(spi4, 1, SI4463_IO0, SI4463_IO1, &si4463_lower_aux);
  if(radio==NULL)
    {
      _err("Unable to initialize aux RFM26\n");
    }
  else
    {
      _info("Initialized aux radio\n");
      ret = genradio_register(radio, "/dev/raux");
      if(ret)
        {
          _err("Failed to register si4463 /dev/raux\n");
        }
      _info("Registered aux radio\n");
    }
#endif

  return 0;
}
#endif

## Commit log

2017-08-01 initial files copied from stm32f429i-disco config with some renames and changes
2017-08-01 Add CERN OHL 1.2 and board readme
2017-08-01 Add existing AP project with dependencies on grx libs
    [ap.sch, cpu.sch, debug.sch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]
2017-08-01 Remove dependencies on grx SCH libs, all components now in dedicated lib
    [ap.sch, cpu.sch, debug.sch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]
2017-08-01 Fix grid origin
    [cpu.sch]
2017-08-01 Removed dependencies on f4libs, project is now fully standalone
    [cpu.sch, debug.sch, ethernet.sch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]
2017-08-02 define IRQ and CS lines for both radios
    [ap.sch, cpu.sch, radio.sch]
2017-08-02 update irq list in cpu schematic
    [cpu.sch]
2017-08-02 add rf4463f30 to radio schematic
    [radio.sch]
2017-08-02 Finish dual secondary radio schematic including common SDN signal, add RF4463F30 footprint
    [ap.sch, cpu.sch, power.sch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]
2017-08-02 Routing SPI bus to radios
2017-08-02 xtal was too close from spi bus
2017-08-02 Move cpu regulator to bring C311 to front, draw mask on back panel edge
2017-08-03 Improve RF routing around RF4463F30 output
    [radio.sch]
2017-08-03 Add LEDs, major work happening in routing.
    [cpu.sch, debug.sch, power.sch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]
2017-08-07 Define correct peripheral pins, disable CCM heap, save latest defconfig
    [board.h]
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2017-08-08 Fix mtd partition initialization
    [stm32_appinit.c]
2017-08-09 Add footprint for wurth shielded box 20mm
2017-08-09 WIP rerouting with shielded boxes
    [ap.sch, cpu.sch, debug.sch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]
2017-08-09 add two LEDs for heartbeat and CPU activity
    [cpu.sch, debug.sch, power.sch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]
2017-08-09 Added 32khz xtal
    [cpu.sch]
2017-08-09 More routing and optimization Routed both CPU XTAL and VBAT connector Improved PSU fitting under shield
    [cpu.sch, debug.sch, ethernet.sch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]
2017-08-09 fix RADIO_SDN near CPU pin
2017-08-11 Route I2C pullups, improve bottom layer clutter
    [cpu.sch]
2017-09-01 fix board so it can be opened with kicad 4.0.7
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2017-09-11 placed main radio shield and rerouted SPI bus around
    [cpu.sch, debug.sch, ethernet.sch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]
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2017-09-12 rearrange radio layout
    [ap.sch, cpu.sch, debug.sch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]
2017-09-12 Update PP45 to use round drills for oshpark
    [ap.sch, cpu.sch, debug.sch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]
2017-09-12 Finish schematic about RF bias, RF routing complete
    [ap.sch, cpu.sch, debug.sch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]
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2017-09-12 Missing a GND trace
2017-09-13 Fixed DRC, added ground planes, started via stitching around RF lines
    [cpu.sch]
2017-09-22 add a button, rename some nets, add some decoupling caps
    [ap.sch, cpu.sch, debug.sch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]
2017-09-22 update debug interface power supply for LEDs
    [cpu.sch, debug.sch]
2017-09-26 schematic update
    [ap.sch, cpu.sch, debug.sch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]
2017-09-28 Add pullups to ethernet lines, and re-install ferrite bead on ethernet vdda
    [ethernet.sch]
2017-09-28 Avoid the use of extvcc, use internal compensation
    [cpu.sch, debug.sch, ethernet.sch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]
2017-10-03 add test points for radio spi, add edge launch SMA for radio IO
    [cpu.sch, debug.sch, ethernet.sch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]
2017-10-04 add a testpoint on mac_refclk and end launch sma to aux radio
    [cpu.sch, debug.sch, ethernet.sch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]
2017-10-05 Add a ferrite bead on Vusb, thanks to f6itu for review
    [cpu.sch, debug.sch, ethernet.sch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]
2017-10-05 Fix TX matching according to Silabs AN627
    [cpu.sch, debug.sch, ethernet.sch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]
2017-10-26 Add a 5V LDO to power the RF4463
    [cpu.sch, ethernet.sch, power.sch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]
2017-11-24 latest changes
    [cpu.sch, debug.sch, power.sch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]
2017-12-01 add an UFL socket to feed an external ref to the onboard si4463
    [ap.sch, cpu.sch, debug.sch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]
2017-12-01 add a tcxo
    [ap.sch, cpu.sch, debug.sch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]
2017-12-08 add a test point for main radio CS signal
    [cpu.sch, debug.sch, ethernet.sch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]
2017-12-11 add a test pin on IRQ
    [cpu.sch, debug.sch, ethernet.sch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]
2017-12-11 add test points on ethernet lines
    [cpu.sch, debug.sch, ethernet.sch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]
2017-12-13 final adjustments before paper review
    [cpu.sch, debug.sch, ethernet.sch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]
2017-12-14 add gpio test points
    [cpu.sch]
2017-12-14 add debug uart test points
    [debug.sch]
2017-12-15 add tx/rx switch project
    [txrx.kicad_pcb, txrx.sch]
2017-12-18 tx/rx switch complete
    [txrx.kicad_pcb]
2017-12-21 Create README.md
    Add a readme for the switch
2018-02-10 rename board source files add openocd script to reboot board
    [hn70ap_boot.c, hn70ap_leds.c, hn70ap_spi.c]
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2018-02-11 add code for i2c eeprom initialization, requires i2cprom branch
2018-02-12 move make.defs to proper place, update config to build ee driver
2018-02-15 reformat readmes, update information about nuttx configurations and i2c bus
2018-02-16 Create board specific feature enable options
2018-02-16 Add info about enclosure
2018-02-19 last schematic updates and pdf
    [ap.sch, cpu.sch, debug.sch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]
2018-02-20 bootloader now writes a short message before booting user code
    [bootloader.h, bootloader_impl.c, bootloader_uart.c]
2018-02-21 add spi lib for bootloader - update Ethernet config PHY address
2018-02-24 light green led at boot prepare mtd access from userspace
2018-02-24 rename LED definitions add MTD ops in mtdchar ioctls remove control of internal leds in the bootloader flash external red during bootloader execution, start external orange to signal download mode.
2018-03-04 updater app exchanges frames
2018-03-04 Firmware: Implement frame decoding and formatting into 256 bytes pages. Tools: detect that update app has started
2018-03-04 Software chain is not able to write an update into the ext flash via the serial port.
2018-03-05 add boardctl support to reboot the system
    [hn70ap_boot.c]
2018-03-06 add internal flash driver for bootloader
2018-03-07 Bootloader improvements: reset flash chip before leaving bootloader, global unlock it in case we are starting from a POR and not a reboot Also add a progress indicator on the console.
    [bootloader_impl.c, bootloader_spiflash.c]
2018-03-07 updater: blank check before erasing fw partition. Also fix nasty bug in bootloader spiflash waitwritecomplete().
    [bootloader_impl.c, bootloader_spiflash.c]
2018-03-08 Enable the userled driver and use it to drive the mac link led
2018-03-08 prototype for settings app
2018-03-08 mount storage, enable routing table
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2018-03-15 improve spi init failure debug
    [hn70ap_genradio.c]
2018-03-27 add a timer and led driver skeleton
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2018-03-29 add radio RX function with green LED fix all apps to init the system before using devices. We still have a problem: when sysdaemon is used as startup, and we run additional apps, the radio device FDs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
2018-04-12 add files for lcd management, with a font start a radio tx thread to centralize transmit requests update defconfig
2018-06-29 fixed both rx threads
